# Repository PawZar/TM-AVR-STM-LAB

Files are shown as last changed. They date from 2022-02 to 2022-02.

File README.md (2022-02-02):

# Projekt centrali alarmowej
## TM-AVR-STM-LAB

Centrala alarmowa z hasłem , 6-wejść typu NC oraz wyjściem przekaźnika naruszenia typu NO.

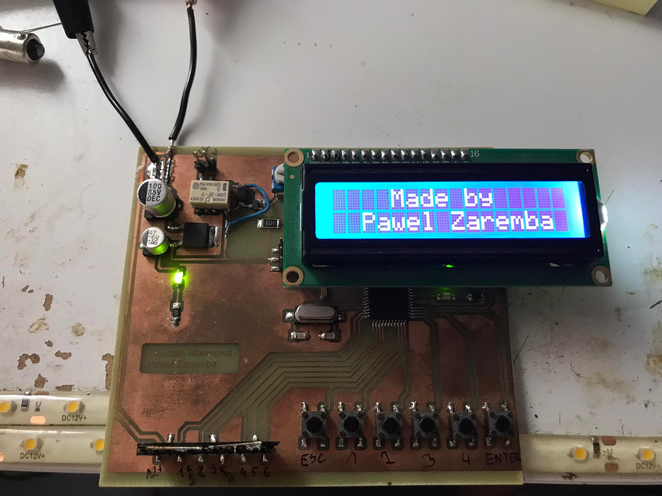
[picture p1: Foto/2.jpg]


## Cechy projektu:
* MCU: AtMega32A w obudowie TQFP44
* Wyświetlacz 2x16 ze sterownikiem HD44780
* Zasilanie 12V DC-IN Max:1,2A
* Zasilacznie czujek 12V DC ~1A obc.
* Wyjście naruszenia typu NO ~1A obciążenie styków
* Wejścia czujek NC wyzwalane stanem niskim
* Pamięć naruszeń
* Kontrola kontrastu wyświetlacza
* Diody LED statusu centrali (alarm,uzbrojenie,stan spoczynku,odliczanie)
* 6 przycisków w roli klawiatury (ESC,1-4,ENTER)
* Dioda LED zasilania

## Działanie centrali:

Centrala posiada 2 tryby, uzbrojony oraz nieuzbrojony. Po wciśnięciu przycisku ENTER następuje przejście do funkcji wpisywania hasła.
Do wpisywania hasła dostępne mamy przyciski 1-4, ENTER oraz ESC który kasuje błędnie wpisaną liczbę .
Po poprawnym wpisaniu hasła następuje odliczanie 20sekund symulujące czas na wyjście z mieszkania. Po upływie czasu uzbrajania centrali,
wejścia czujek aktywują się. Wejścia ustawione są w tryb NC ze zwarciem do GND, kiedy jedna z czujek przez minimum 1,6sek 
zostanie aktywowana zaczyna się przejście do funkcji wpisywania hasła na które ma się ponowne 20sekund. Po upływie tego czasu,
bądź 3-krotnym złym wpisaniu hasła następuje wyzwolenie alarmu i załączenie wyjścia. Podczas trwanai alarmu można przejść do funkcji 
wpisywania hasła przyciskiem ENTER. Po rozbrojeniu centrali po alarmie zapamiętane zostaje zdarzenie naruszenia systemu, po następnym uzbrojeniu
centrali błąd się kasuje.

## Mikrokontroler Atmega32A:

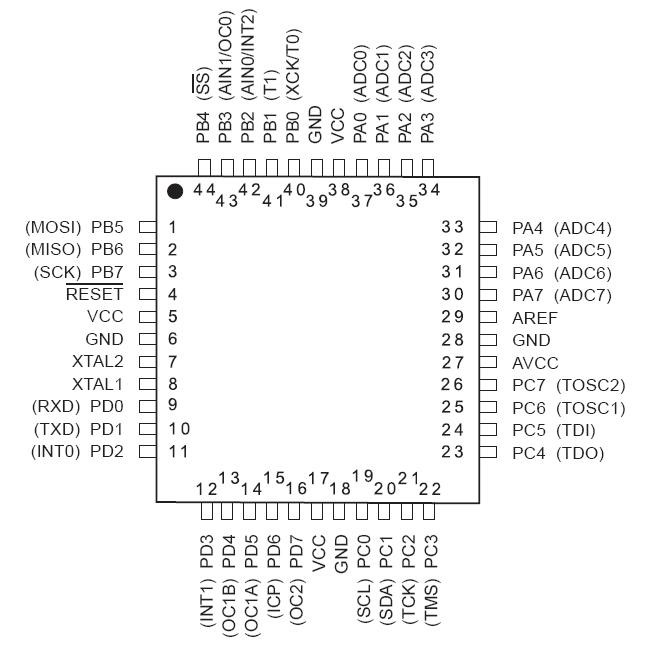
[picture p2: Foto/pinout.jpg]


 * Taktowanie w projekcie: 16MHz zewnętrzne
 * Zasilanie układu: 5V DC
 * Programowanie : złącze ISP
 * 1kB EEPROM
 * 2kB SRAM
 * 32kB flash
 
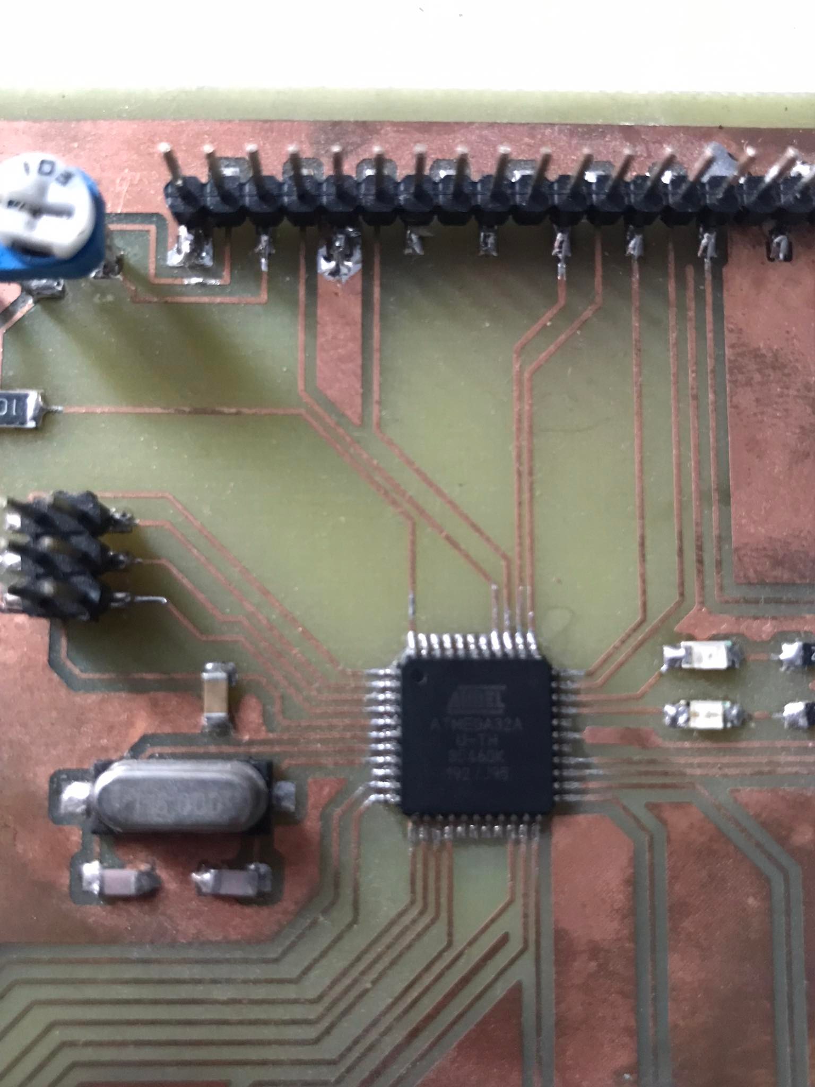
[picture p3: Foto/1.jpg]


## Zdjęcia schematu oraz płytki z programu EAGLE:

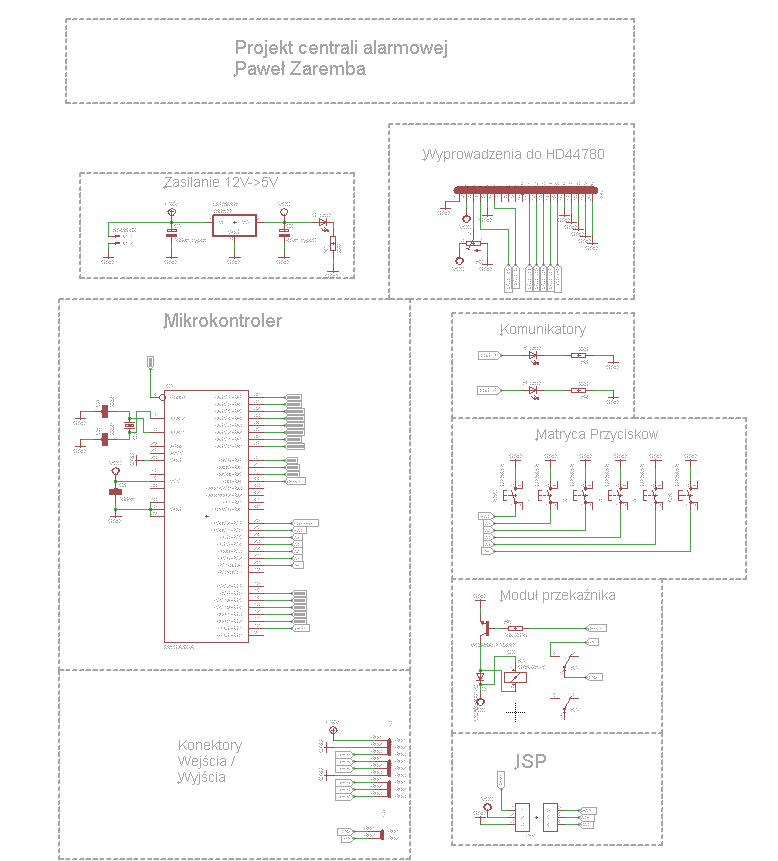
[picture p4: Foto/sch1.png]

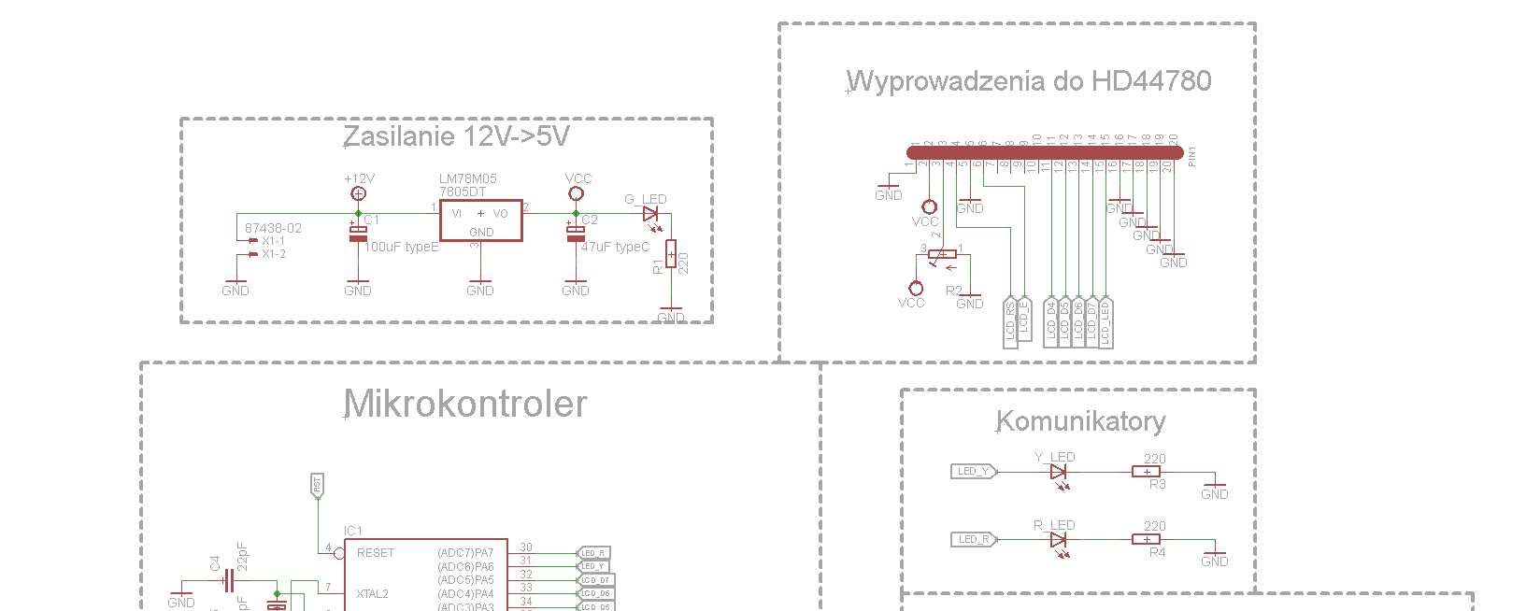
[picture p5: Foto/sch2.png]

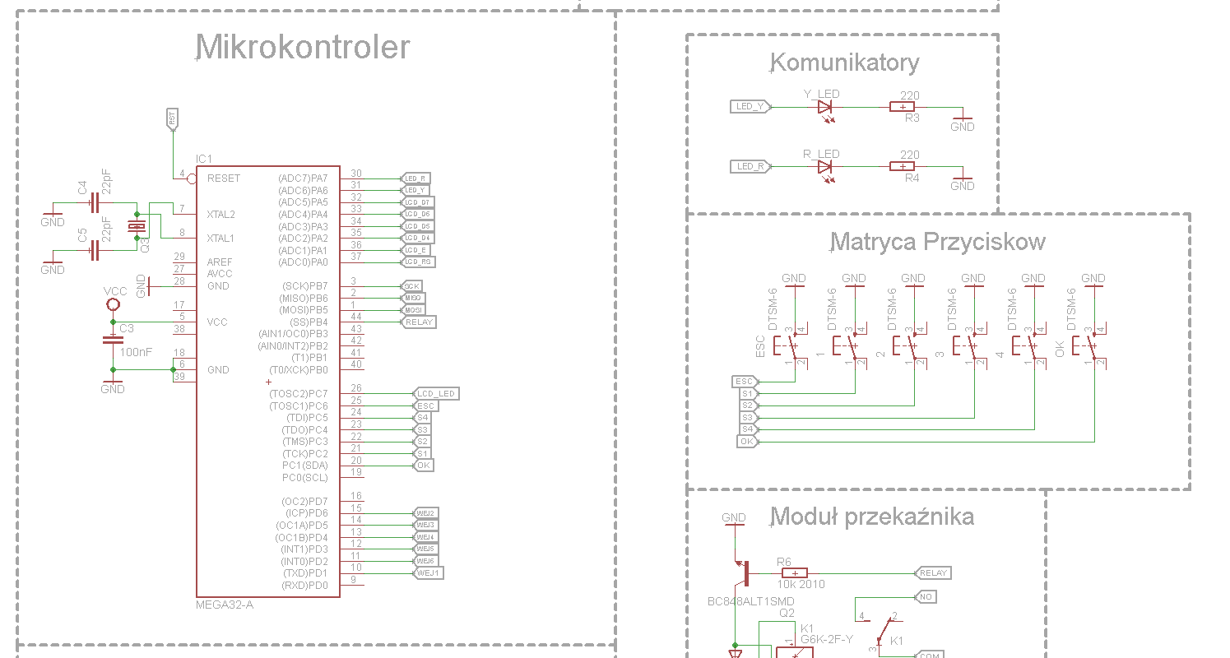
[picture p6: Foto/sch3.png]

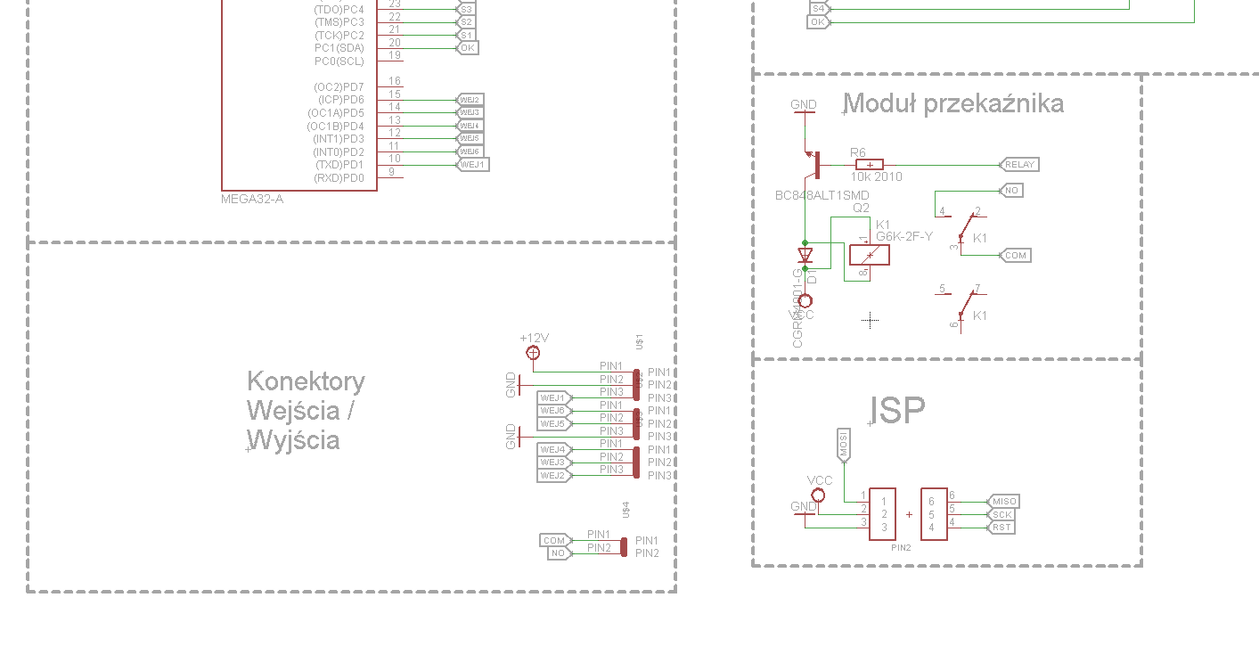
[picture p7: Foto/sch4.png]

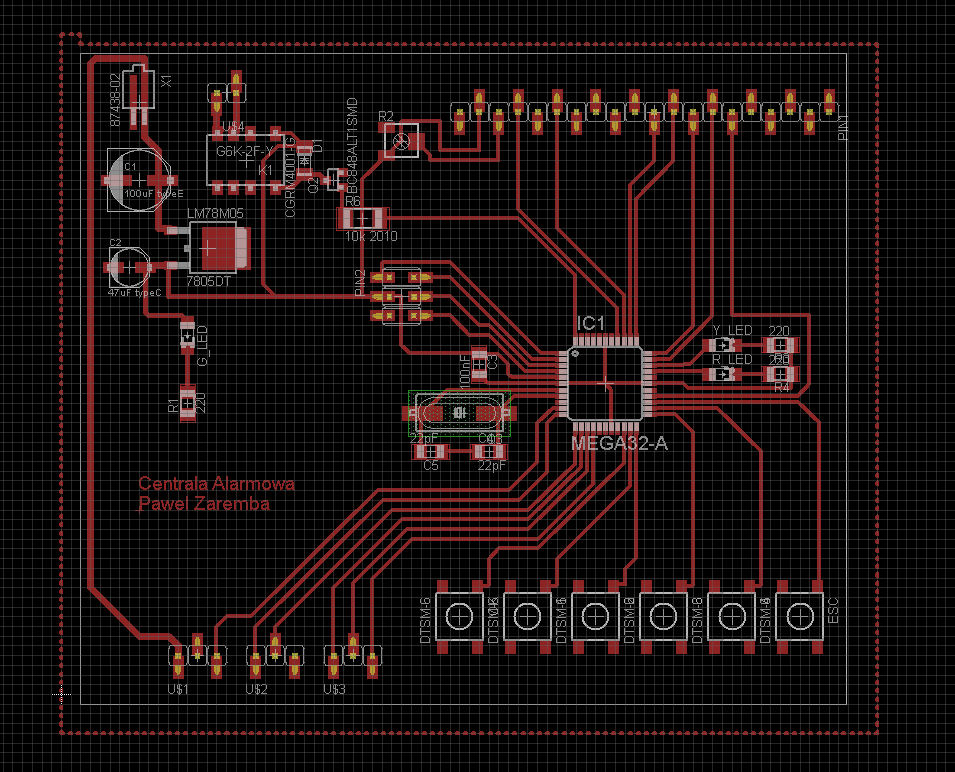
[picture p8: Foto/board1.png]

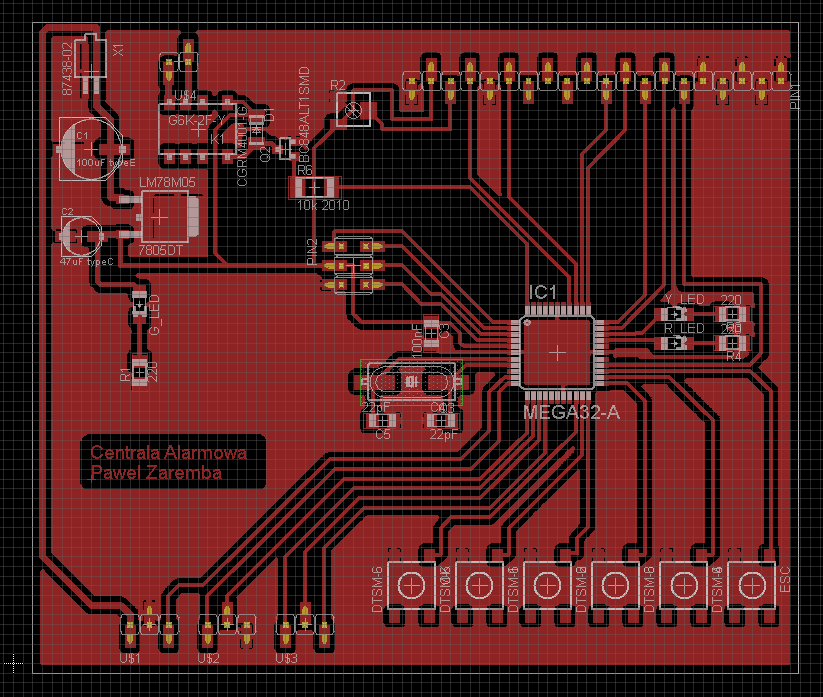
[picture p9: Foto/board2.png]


## Zdjęcia wykonanego układu:


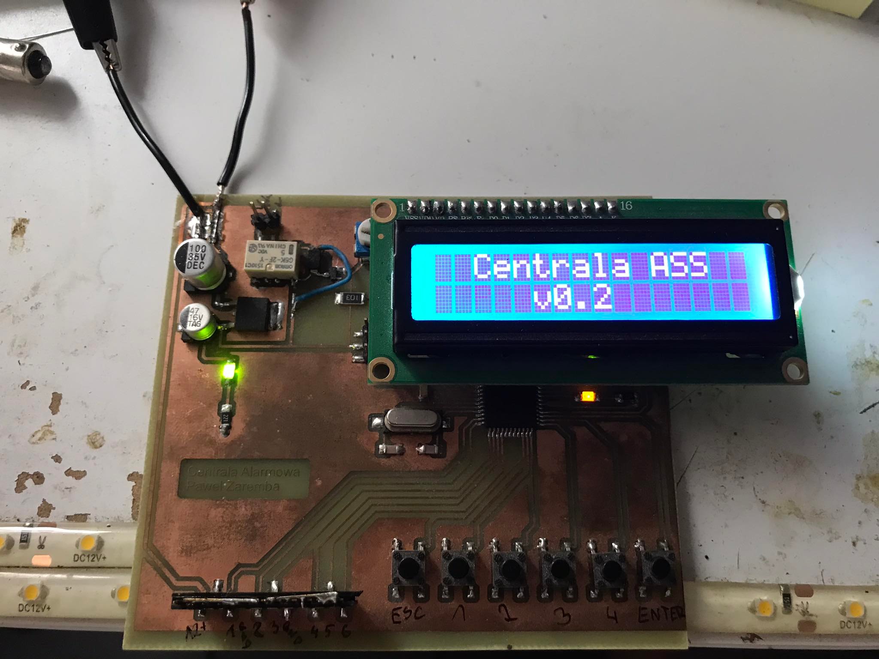
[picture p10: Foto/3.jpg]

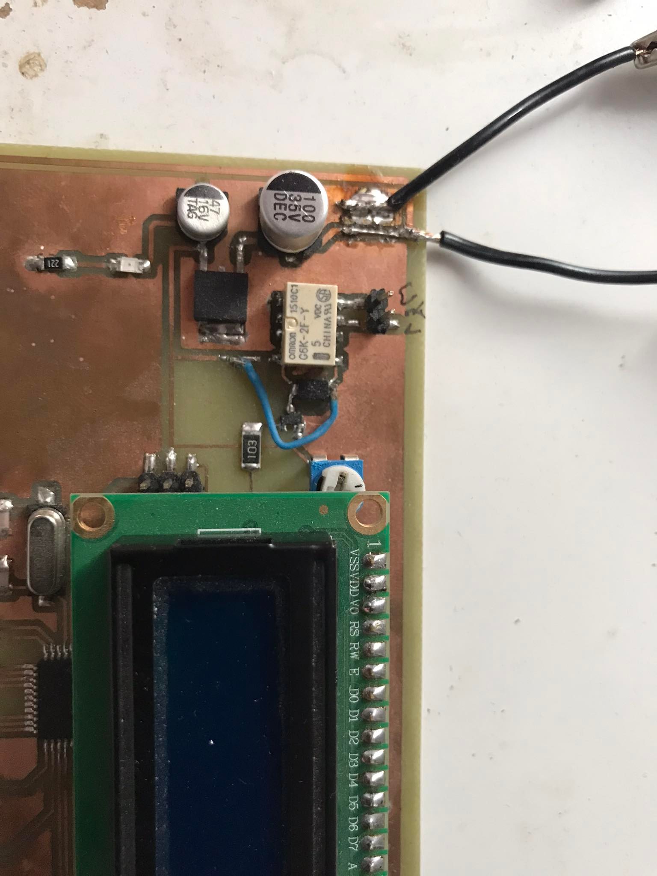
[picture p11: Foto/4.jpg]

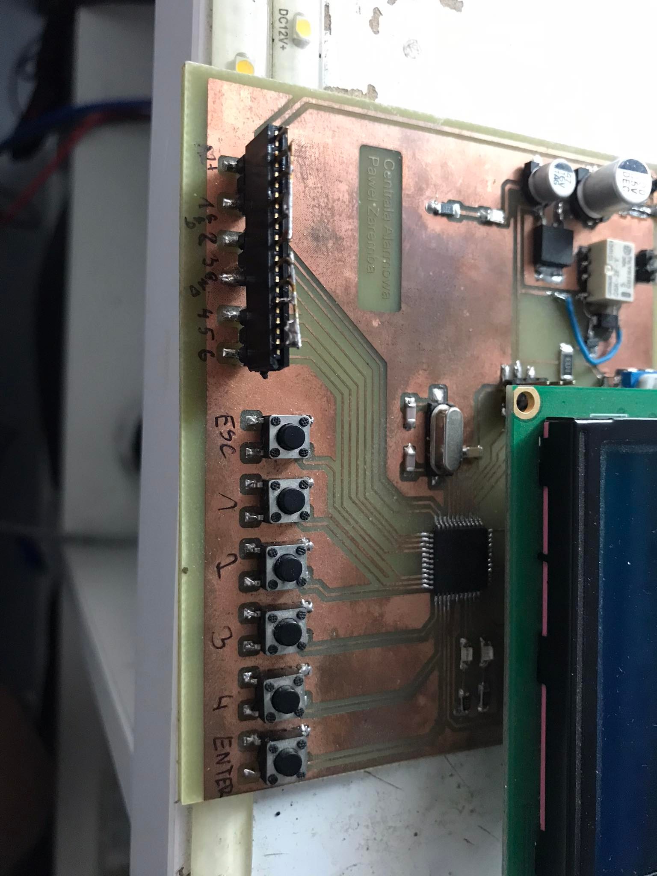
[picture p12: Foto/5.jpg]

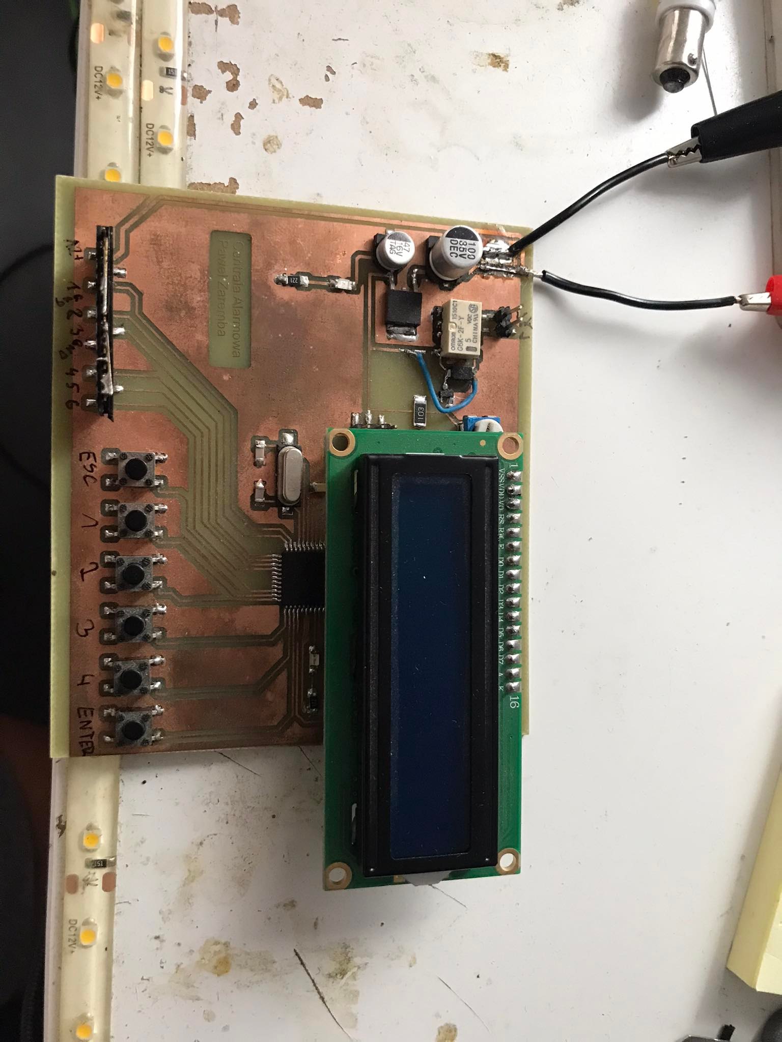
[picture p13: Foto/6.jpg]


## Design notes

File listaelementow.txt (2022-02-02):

Partlist

Exported from alarm1.sch at 2021-03-21 15:37:58

EAGLE Version 6.3.0 Copyright (c) 1988-2012 CadSoft

Assembly variant: 

Part     Value           Device          Package          Library                        Sheet

1        DTSM-6          DTSM-6          DTSM-6           switch-tact                    1
2        DTSM-6          DTSM-6          DTSM-6           switch-tact                    1
3        DTSM-6          DTSM-6          DTSM-6           switch-tact                    1
4        DTSM-6          DTSM-6          DTSM-6           switch-tact                    1
C1       100uF typeE     CPOL-EUE        PANASONIC_E      resistor                       1
C2       47uF typeC      CPOL-EUC        PANASONIC_C      resistor                       1
C3       100nF           C-EUC1206       C1206            resistor                       1
C4       22pF            C-EUC1206       C1206            resistor                       1
C5       22pF            C-EUC1206       C1206            resistor                       1
D1       CGRM4001-G      CGRM4001-G      SOD-123_MINI-SMA diode                          1
ESC      DTSM-6          DTSM-6          DTSM-6           switch-tact                    1
G_LED                    LEDCHIPLED_1206 CHIPLED_1206     led                            1
IC1      MEGA32-A        MEGA32-A        TQFP44           atmel                          1
K1       G6K-2F-Y        G6K-2F-Y        G6K-2F-Y         relay                          1
LM78M05  7805DT          7805DT          TO252            linear                         1
OK       DTSM-6          DTSM-6          DTSM-6           switch-tact                    1
PIN1                     SINGLE1X20      SINGLE1X20       con-pinheaderSMD2,54(gold_pin) 1
PIN2                     2X3_GOLDPIN     GOLD2X3          con-pinheaderSMD2,54(gold_pin) 1
Q2       BC848ALT1SMD    BC848ALT1SMD    SOT23            transistor-npn                 1
Q3                       CRYSTALHC49UP   HC49UP           crystal                        1
R1       220             R-EU_R1206      R1206            resistor                       1
R2                       R-TRIMM3314J    RTRIM3314J       resistor                       1
R3       220             R-EU_R1206      R1206            resistor                       1
R4       220             R-EU_R1206      R1206            resistor                       1
R6       10k 2010        R-EU_R2010      R2010            resistor                       1
R_LED                    LEDCHIPLED_1206 CHIPLED_1206     led                            1
U$1      GOLDPIN_SMD_1X3 GOLDPIN_SMD_1X3 GOLDPINSMD1X3    con-pinheaderSMD2,54-1x4       1
U$2      GOLDPIN_SMD_1X3 GOLDPIN_SMD_1X3 GOLDPINSMD1X3    con-pinheaderSMD2,54-1x4       1
U$3      GOLDPIN_SMD_1X3 GOLDPIN_SMD_1X3 GOLDPINSMD1X3    con-pinheaderSMD2,54-1x4       1
U$4      GOLDPIN_SMD_1X2 GOLDPIN_SMD_1X2 GOLDPINSMD1X2    con-pinheaderSMD2,54-1x4       1
X2       87438-02        87438-02        87438-02         con-molex                      1
Y_LED                    LEDCHIPLED_1206 CHIPLED_1206     led                            1

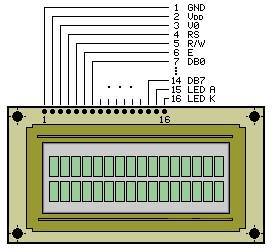
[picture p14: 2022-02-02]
Foto/wysw.jpg

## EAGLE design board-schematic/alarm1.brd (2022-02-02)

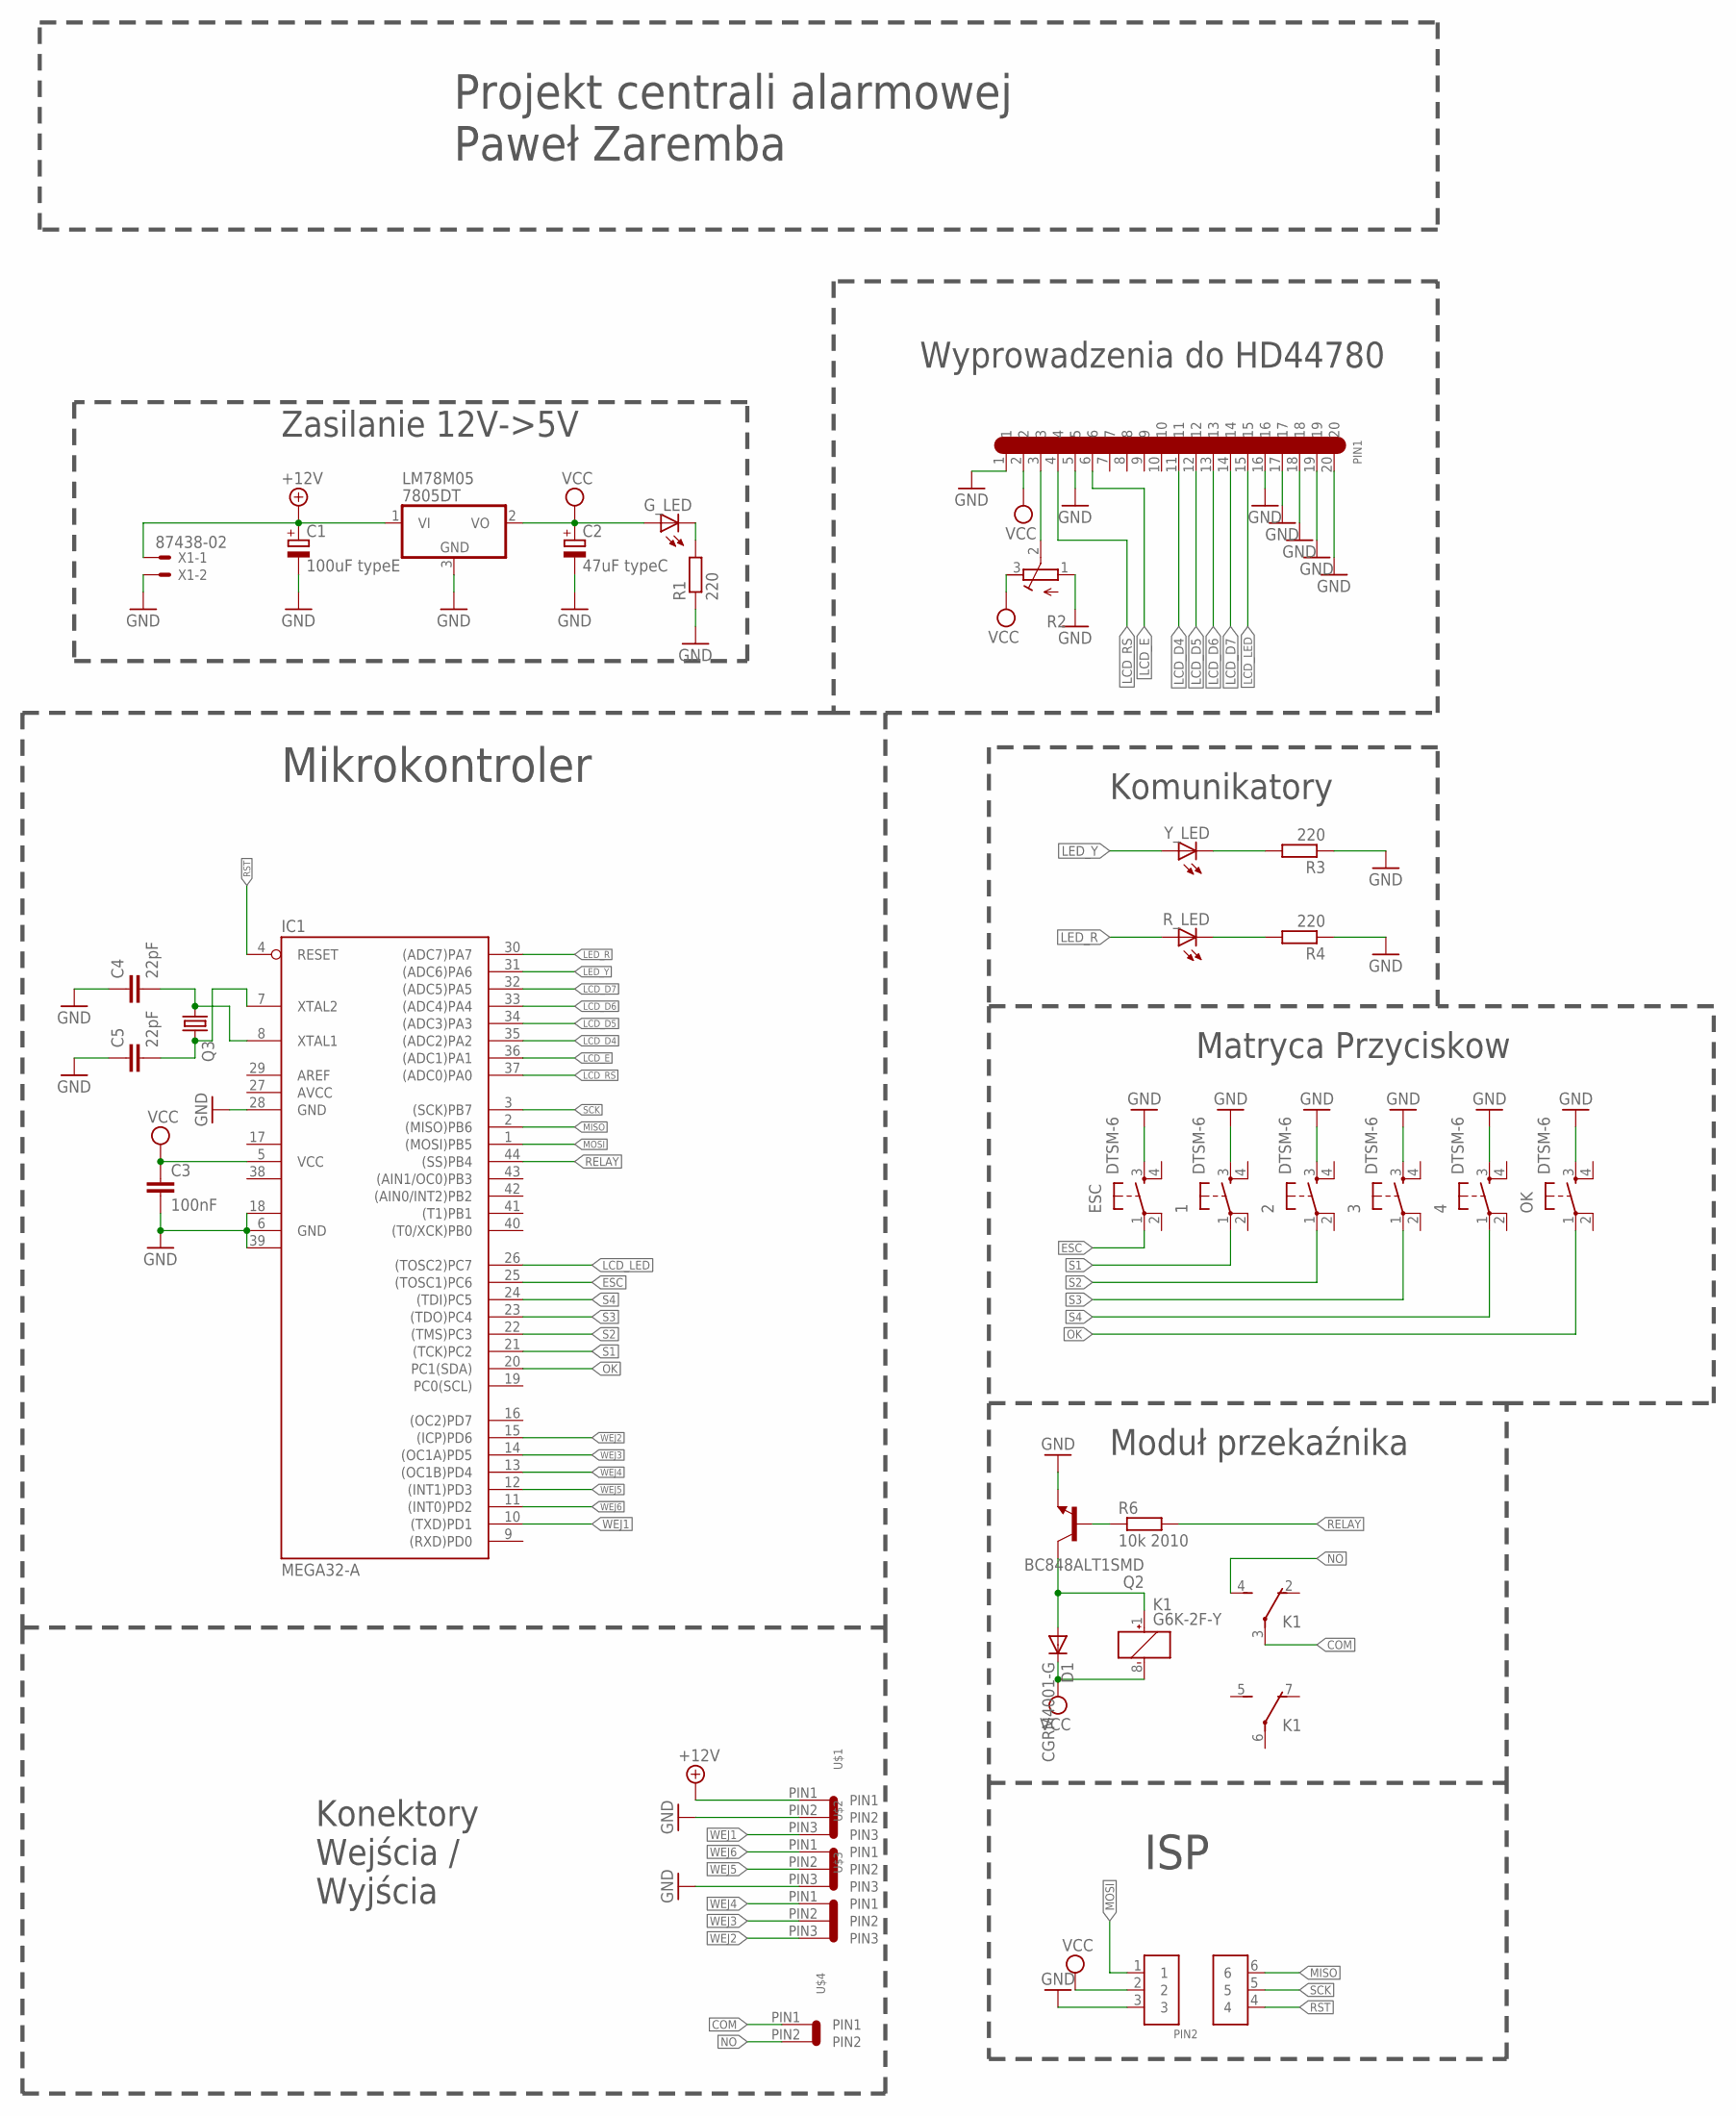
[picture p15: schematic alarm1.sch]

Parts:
1, 2, 3, 4: DTSM-6
C1: 100uF typeE; PANASONIC_E
C2: 47uF typeC; PANASONIC_C
C3: 100nF; C1206
C4, C5: 22pF; C1206
D1: CGRM4001-G; SOD-123_MINI-SMA
ESC: DTSM-6
G_LED: LEDCHIPLED_1206; CHIPLED_1206
IC1: MEGA32-A; TQFP44
K1: G6K-2F-Y
LM78M05: 7805DT; TO252
OK: DTSM-6
PIN1: SINGLE1X20
PIN2: 2X3_GOLDPIN; GOLD2X3
Q2: BC848ALT1SMD; SOT23
Q3: CRYSTALHC49UP; HC49UP
R1, R3, R4: 220; R1206
R2: R-TRIMM3314J; RTRIM3314J
R6: 10k 2010; R2010
R_LED: LEDCHIPLED_1206; CHIPLED_1206
U$1, U$2, U$3: GOLDPIN_SMD_1X3; GOLDPINSMD1X3
U$4: GOLDPIN_SMD_1X2; GOLDPINSMD1X2
X1: 87438-02
Y_LED: LEDCHIPLED_1206; CHIPLED_1206

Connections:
+12V: C1.+, LM78M05.1 (VI), U$1.PIN1, X1.1
AVCC: IC1.27 (AVCC)
COM: K1.3, U$4.PIN1
CRYSTAL_L: C5.2, IC1.7 (XTAL2), Q3.2
CRYSTAL_R: C4.2, IC1.8 (XTAL1), Q3.1
ESC: ESC.1, IC1.25 ((TOSC1)PC6)
GND: 1.3, 2.3, 3.3, 4.3, C1.-, C2.-, C3.2, C4.1, C5.1, ESC.3, IC1.6 (GND), IC1.18 (GND1), IC1.28 (GND), IC1.39 (GND2), LM78M05.3 (GND), OK.3, PIN1.1, PIN1.5, PIN1.16, PIN1.17, PIN1.18, PIN1.19, PIN1.20, PIN2.3, Q2.2 (E), R1.1, R2.1 (E), R3.1, R4.1, U$1.PIN2, U$2.PIN3, X1.2
LCD_D4: IC1.35 ((ADC2)PA2), PIN1.11
LCD_D5: IC1.34 ((ADC3)PA3), PIN1.12
LCD_D6: IC1.33 ((ADC4)PA4), PIN1.13
LCD_D7: IC1.32 ((ADC5)PA5), PIN1.14
LCD_E: IC1.36 ((ADC1)PA1), PIN1.6
LCD_LED: IC1.26 ((TOSC2)PC7), PIN1.15
LCD_RS: IC1.37 ((ADC0)PA0), PIN1.4
LED_R: IC1.30 ((ADC7)PA7), R_LED.A
LED_Y: IC1.31 ((ADC6)PA6), Y_LED.A
MISO: IC1.2 ((MISO)PB6), PIN2.6
MOSI: IC1.1 ((MOSI)PB5), PIN2.1
unnamed: D1.A, K1.1 (+), Q2.3 (C)
unnamed: G_LED.C, R1.2
unnamed: PIN1.3, R2.2 (S)
unnamed: R3.2, Y_LED.C
unnamed: R4.2, R_LED.C
unnamed: Q2.1 (B), R6.1
NO: K1.4 (S), U$4.PIN2
OK: IC1.20 (PC1(SDA)), OK.1
RELAY: IC1.44 ((SS)PB4), R6.2
RST: IC1.4 (RESET), PIN2.4
S1: 1.1, IC1.21 ((TCK)PC2)
S2: 2.1, IC1.22 ((TMS)PC3)
S3: 3.1, IC1.23 ((TDO)PC4)
S4: 4.1, IC1.24 ((TDI)PC5)
SCK: IC1.3 ((SCK)PB7), PIN2.5
VCC: C2.+, C3.1, D1.C, G_LED.A, IC1.5 (VCC), K1.8 (-), LM78M05.2 (VO), PIN1.2, PIN2.2, R2.3 (A)
VCC1: IC1.17 (VCC1)
VCC2: IC1.38 (VCC2)
WEJ1: IC1.10 ((TXD)PD1), U$1.PIN3
WEJ2: IC1.15 ((ICP)PD6), U$3.PIN3
WEJ3: IC1.14 ((OC1A)PD5), U$3.PIN2
WEJ4: IC1.13 ((OC1B)PD4), U$3.PIN1
WEJ5: IC1.12 ((INT1)PD3), U$2.PIN2
WEJ6: IC1.11 ((INT0)PD2), U$2.PIN1

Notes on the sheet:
Zasilanie 12V->5V
Wyprowadzenia do HD44780
Komunikatory
Matryca Przyciskow
ISP
Moduł przekaźnika
Konektory Wejścia / Wyjścia
Mikrokontroler
Projekt centrali alarmowej Paweł Zaremba

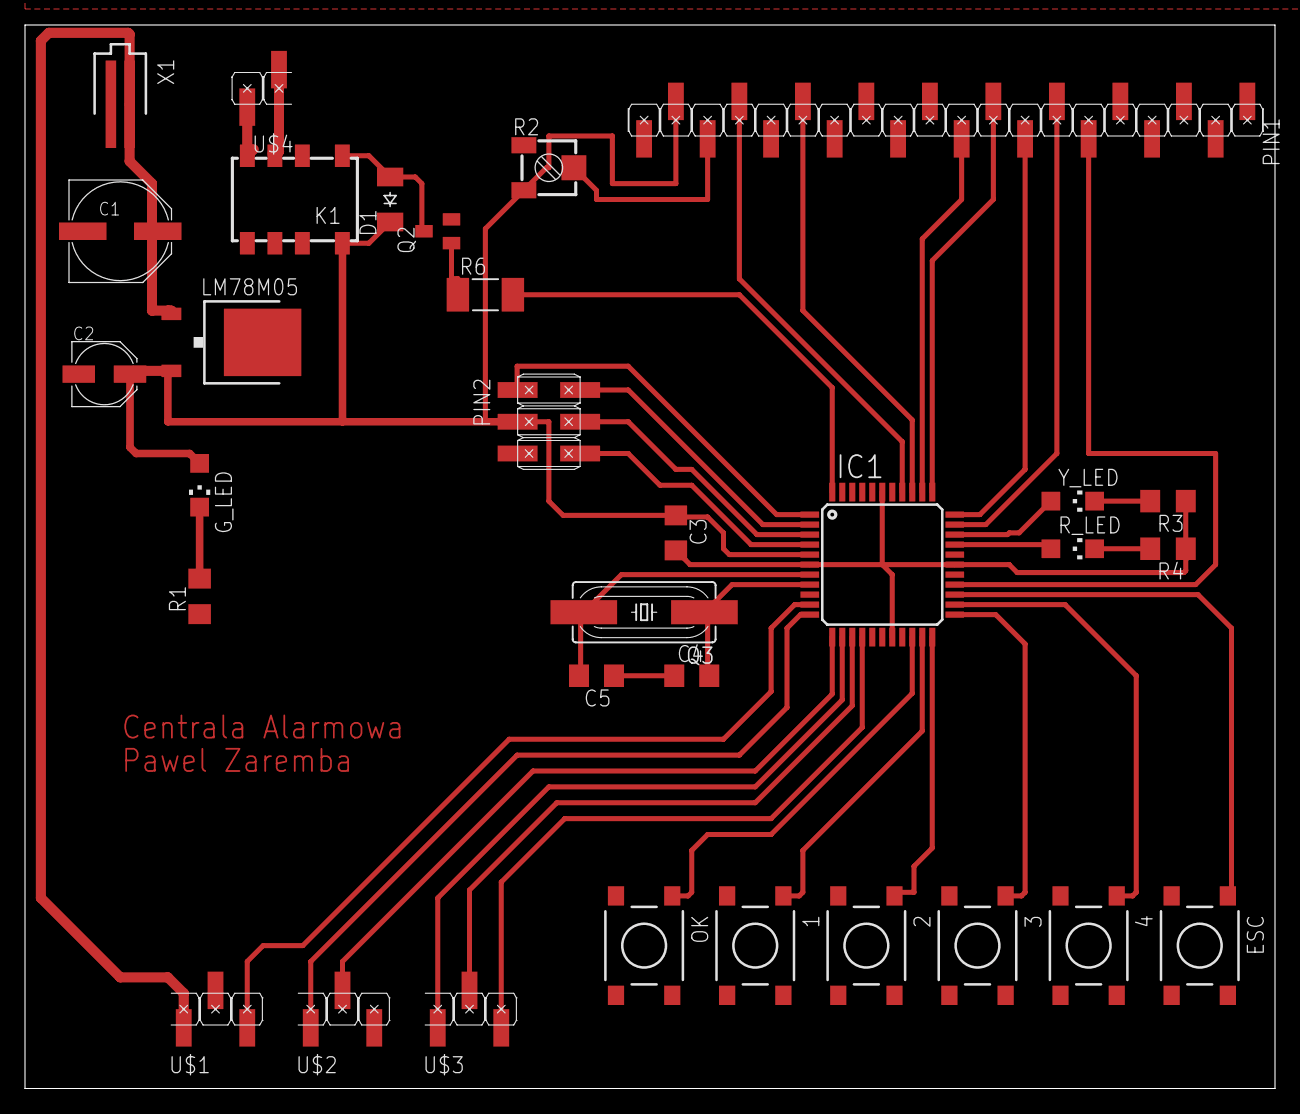
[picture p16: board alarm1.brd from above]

Board: 2 copper layers, 100.0 x 85.1 mm, 32 parts (0 on the bottom side), 39 nets.

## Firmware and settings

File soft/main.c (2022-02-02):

/*
 * main.c
 *
 *  Created on: 09-03-2021
 *      Author: Pawel
 */
#include <avr/io.h>
#include <util/delay.h>
#include <avr/alarm/HD44780.h>
#include "avr/alarm/HD44780.c"

#define LEDy (1<<PA6) //zolta dioda statusu
#define LEDr (1<<PA7) //czerwona dioda uzbrojenia

#define esc (1<<PC2) // esc
#define jeden (1<<PC3) // 1
#define dwa (1<<PC4) // 2
#define trzy (1<<PC5) // 3
#define cztery (1<<PC6) // 4
#define ok (1<<PC7) //  ok / uzbrajanie

#define relay (1<<PD0) // przekaznik

#define wej1 (1<<PD2) // wejscie Z1
#define wej2 (1<<PD3) // wejscie Z2
#define wej3 (1<<PD4) // wejscie Z3
#define wej4 (1<<PD5) // wejscie Z4
#define wej5 (1<<PD6) // wejscie Z5
#define wej6 (1<<PD7) // wejscie Z6


int main(void)
{
//wyjscia
DDRA |= LEDy;
DDRA |= LEDr;
DDRD |= relay;
//wejscia
PORTC |= esc;
PORTC |= jeden;
PORTC |= dwa;
PORTC |= trzy;
PORTC |= cztery;
PORTC |= ok;
PORTD |= wej1;
PORTD |= wej2;
PORTD |= wej3;
PORTD |= wej4;
PORTD |= wej5;
PORTD |= wej6;
//inicjalizacja LCD
_delay_ms(10);

LCD_Initalize();
LCD_Clear();
LCD_GoTo(0,0);

_delay_ms(10);
//deklaracja zmiennych
int niepoprawnehaslo=0;
int wyjsciowa=0;
int uzbrojenie=0;
int haslopoprawne=0;
int alarm=0;
int naruszenie1=0;
int naruszenie2=0;
int naruszenie3=0;
int naruszenie4=0;
int naruszenie5=0;
int naruszenie6=0;
int wlamanie=0;
int timer=0;	//100ms kazdy cykl

powitanie(); // wyswietl ekran startowy


while(1){
	if((uzbrojenie==0)&&(alarm==0)){
	ekran_start(wlamanie, timer);
	}

	if(!(PINC & ok))
	{
		//funkcje wpisania hasla

		wyjsciowa=funkcjaHasla();
		_delay_ms(250);
	}

	if(wyjsciowa>=1)
	{
	switch(wyjsciowa)
		{
	case 0:

	break;

	case 1:
		//haslo niepoprawne
		niepoprawnehaslo++;
		wysHasloNiepoprawne();
		wyjsciowa=0;
		if(niepoprawnehaslo>=3){
			alarm=1;
			niepoprawnehaslo=0;
			uzbrojenie=1;
		}
		break;

	case 2:
		//haslo poprawne

		niepoprawnehaslo=0;
		wysHasloPoprawne();
		if(uzbrojenie==0){
		wlamanie=0;
		OdliczanieDoUzbrojenia();
		uzbrojenie=1;
		haslopoprawne=0;
		}

		else if(uzbrojenie==1){
		if(PIND & relay){
			PORTD ^= relay;
		}
		uzbrojenie=0;
		alarm=0;
		naruszenie1=0;
		naruszenie2=0;
		naruszenie3=0;
		naruszenie4=0;
		naruszenie5=0;
		naruszenie6=0;
		}
		wyjsciowa=0;
		break;

	case 3:
		//cofnij dzialanie , nie rob nic
		wyjsciowa=0;
		break;



		}
	}

	if((uzbrojenie==1)&&(alarm==0))
	{
		stanUzbrojony();

	if(PIND & wej1)
	{
	naruszenie1++;
		if(naruszenie1>=15){
			wyjsciowa=funkcjaHasla();
			naruszenie1=16;
		}
	}
	else if(!(PIND & wej1)){
		if(naruszenie1>=1){
		naruszenie1--;
		}
	}


	if(PIND & wej2)
	{
	naruszenie2++;
		if(naruszenie2>=15){
			wyjsciowa=funkcjaHasla();
			naruszenie2=16;
		}
	}
	else if(!(PIND & wej2)){
		if(naruszenie2>=1){
		naruszenie2--;
		}
	}


	if(PIND & wej3)
	{
	naruszenie3++;
		if(naruszenie3>=15){
			wyjsciowa=funkcjaHasla();
			naruszenie3=16;
		}
	}
	else if(!(PIND & wej3)){
		if(naruszenie3>=1){
		naruszenie3--;
		}
	}


	if(PIND & wej4)
	{
	naruszenie4++;
		if(naruszenie4>=15){
			wyjsciowa=funkcjaHasla();
			naruszenie4=16;
		}
	}
	else if(!(PIND & wej4)){
		if(naruszenie4>=1){
		naruszenie4--;
		}
	}


	if(PIND & wej5)
	{
	naruszenie5++;
		if(naruszenie5>=15){
			wyjsciowa=funkcjaHasla();
			naruszenie5=16;
		}
	}
	else if(!(PIND & wej5)){
		if(naruszenie5>=1){
		naruszenie5--;
		}
	}

	if(PIND & wej6)
	{
	naruszenie6++;
		if(naruszenie6>=15){
			wyjsciowa=funkcjaHasla();
			naruszenie6=16;
		}
	}
	else if(!(PIND & wej6)){
		if(naruszenie6>=1){
		naruszenie6--;
		}
	}

	}


	if(alarm==1)
	{
		if(!(PIND & relay)){
			PORTD ^= relay;
		}
		if(!(PINA & LEDr)){
		PORTA ^= LEDr;
		}
		wysAlarm();
		wlamanie=1;
	}


	_delay_ms(100); //globalny timer
	timer++;
	if(timer>=100){
		timer=0;
	}
	}
}

void powitanie()
{
	PORTA ^= LEDr;
	PORTA ^= LEDy;
	LCD_Clear();
	LCD_GoTo(2,0);
	LCD_WriteText("Centrala ASS");
	LCD_GoTo(5,1);
	LCD_WriteText("v0.2");
	_delay_ms(2500);
	PORTA ^= LEDr;
	PORTA ^= LEDy;
	LCD_Clear();
	LCD_GoTo(4,0);
	LCD_WriteText("Made by");
	LCD_GoTo(2,1);
	LCD_WriteText("Pawel Zaremba");
	_delay_ms(1500);
}


void ekran_start(int wlam, int time)
{
	int t;
	int t1;
	if(PINA & LEDr){
		PORTA^= LEDr;
	}
	if(PINA & LEDy){
		PORTA^= LEDy;
	}
	if(PINA & relay){
		PORTA^= relay;
	}
	t=time%20;
	t1=time%40;
	LCD_GoTo(0,0);
	LCD_WriteText("  Centrala ASS  ");
if(wlam==0)
{
	LCD_GoTo(0,1);
	LCD_WriteText("Brak powiadomien");
	if((t==0)&&(t1!=0)){
		PORTA ^= LEDy;
	}
	if((t==0)&&(t1==0)){
		PORTA ^=LEDy;
	}
}
if(wlam==1)
{
			if((t==0)&&(t1!=0)){
				PORTA ^= LEDy;
				PORTA^= LEDr;

			}
			if((t==0)&&(t1==0)){
				PORTA ^=LEDy;
				PORTA^= LEDr;
			}
	LCD_GoTo(0,1);
	LCD_WriteText("wys. Naruszenie!");

}
}

int funkcjaHasla(){
	int wyjsciowa=0;
	int haslo[5];
	haslo[0] = 3;
	haslo[1] = 4;
	haslo[2] = 1;
	haslo[3] = 1;
	haslo[4] = 3;
	int wpisywanehaslo[5];
	wpisywanehaslo[0] = 0;
	wpisywanehaslo[1] = 0;
	wpisywanehaslo[2] = 0;
	wpisywanehaslo[3] = 0;
	wpisywanehaslo[4] = 0;
	int a=0; // wpisano liczbe
	//int wyjscie=0;
	int sprawdzanie=0;
	int time=0;
	int poprawne[5];
	poprawne[0]=0;
	poprawne[1]=0;
	poprawne[2]=0;
	poprawne[3]=0;
	poprawne[4]=0;
	if(PINA & LEDr){
		PORTA^= LEDr;
	}
	if(PINA & LEDy){
		PORTA^= LEDy;
	}
	_delay_ms(500);
		for(int i=0;i<=150;i++)
		{
		if(!(PINC & jeden))
		{

			wpisywanehaslo[a]=1;

			if(wpisywanehaslo[a]==haslo[a]){
				poprawne[a]=1;
			}
			else{
				poprawne[a]=0;
			}
			a++;
			_delay_ms(250);
		}
		else if(!(PINC & dwa))
		{

			wpisywanehaslo[a]=2;
			if(wpisywanehaslo[a]==haslo[a]){
				poprawne[a]=1;
			}
			else{
				poprawne[a]=0;
			}
			a++;
			_delay_ms(250);
		}
		else if(!(PINC & trzy))
		{

			wpisywanehaslo[a]=3;
			if(wpisywanehaslo[a]==haslo[a]){
				poprawne[a]=1;
			}
			else{
				poprawne[a]=0;
			}
			a++;
			_delay_ms(250);
		}
		else if(!(PINC & cztery))
		{

			wpisywanehaslo[a]=4;
			if(wpisywanehaslo[a]==haslo[a]){
				poprawne[a]=1;
			}
			else{
				poprawne[a]=0;
			}
			a++;
			_delay_ms(250);
		}
		if(a==0){
			LCD_Clear();
			LCD_GoTo(0,0);
			LCD_WriteText("Wpisz Haslo:");

		}
		else if(a==1){
			LCD_Clear();
			LCD_GoTo(0,0);
			LCD_WriteText("Wpisz Haslo:");
			LCD_GoTo(0,1);
			LCD_WriteText("*");
		}
		else if(a==2){
			LCD_Clear();
			LCD_GoTo(0,0);
			LCD_WriteText("Wpisz Haslo:");
			LCD_GoTo(0,1);
			LCD_WriteText("**");
		}
		else if(a==3){
			LCD_Clear();
			LCD_GoTo(0,0);
			LCD_WriteText("Wpisz Haslo:");
			LCD_GoTo(0,1);
			LCD_WriteText("***");
		}
		else if(a==4){
			LCD_Clear();
			LCD_GoTo(0,0);
			LCD_WriteText("Wpisz Haslo:");
			LCD_GoTo(0,1);
			LCD_WriteText("****");
		}
		else if(a==5){
			LCD_Clear();
			LCD_GoTo(0,0);
			LCD_WriteText("Wpisz Haslo:");
			LCD_GoTo(0,1);
			LCD_WriteText("*****");
		}
		if(!(PINC & esc))
		{

			wyjsciowa=3;
			_delay_ms(250);
			break;
		}
		if(!(PINC & ok)){
			_delay_ms(250);
			break;

		}

		_delay_ms(100);



	}
	if(wyjsciowa==3){

	}
	else{
		if((poprawne[0]==1)&&(poprawne[1]==1)&&(poprawne[2]==1)&&(poprawne[3]==1)&&(poprawne[4]==1)){
			wyjsciowa=2;
		}
		else{
			wyjsciowa=1;
		}
	}

	return wyjsciowa;
}

void wysHasloNiepoprawne(){
	LCD_Clear();
	LCD_GoTo(5,0);
	LCD_WriteText("Haslo");
	LCD_GoTo(2,1);
	LCD_WriteText("Niepoprawne!");
	_delay_ms(800);
	LCD_Clear();
	_delay_ms(600);
	LCD_GoTo(5,0);
	LCD_WriteText("Haslo");
	LCD_GoTo(2,1);
	LCD_WriteText("Niepoprawne!");
	_delay_ms(800);
	LCD_Clear();
	_delay_ms(600);
	LCD_GoTo(5,0);
	LCD_WriteText("Haslo");
	LCD_GoTo(2,1);
	LCD_WriteText("Niepoprawne!");
	_delay_ms(800);
	LCD_Clear();
}

void wysHasloPoprawne(){
	LCD_Clear();
		LCD_GoTo(5,0);
		LCD_WriteText("Haslo");
		LCD_GoTo(2,1);
		LCD_WriteText("Poprawne");
		_delay_ms(1000);
		LCD_Clear();
}

void OdliczanieDoUzbrojenia(){
	if(PINA & LEDr){
		PORTA^= LEDr;
	}
	if(PINA & LEDy){
		PORTA^= LEDy;
	}
	LCD_Clear();
	PORTA^= LEDy;
	LCD_GoTo(0,0);
	LCD_WriteText("Uzbrajanie");
	LCD_GoTo(0,1);
	LCD_WriteText("20s");
	_delay_ms(200);
	PORTA^= LEDy;
	_delay_ms(200);
	PORTA^= LEDy;
	_delay_ms(200);
	PORTA^= LEDy;
	_delay_ms(200);
	PORTA^= LEDy;
	_delay_ms(200);
	PORTA^= LEDy;
	LCD_GoTo(0,1);
	LCD_WriteText("19s");
	_delay_ms(200);
	PORTA^= LEDy;
	_delay_ms(200);
	PORTA^= LEDy;
	_delay_ms(200);
	PORTA^= LEDy;
	_delay_ms(200);
	PORTA^= LEDy;
	_delay_ms(200);
	PORTA^= LEDy;
	LCD_GoTo(0,1);
	LCD_WriteText("18s");
	_delay_ms(200);
	PORTA^= LEDy;
	_delay_ms(200);
	PORTA^= LEDy;
	_delay_ms(200);
	PORTA^= LEDy;
	_delay_ms(200);
	PORTA^= LEDy;
	_delay_ms(200);
	PORTA^= LEDy;
	LCD_GoTo(0,1);
	LCD_WriteText("17s");
	_delay_ms(200);
	PORTA^= LEDy;
	_delay_ms(200);
	PORTA^= LEDy;
	_delay_ms(200);
	PORTA^= LEDy;
	_delay_ms(200);
	PORTA^= LEDy;
	_delay_ms(200);
	PORTA^= LEDy;
	LCD_GoTo(0,1);
	LCD_WriteText("16s");
	_delay_ms(200);
	PORTA^= LEDy;
	_delay_ms(200);
	PORTA^= LEDy;
	_delay_ms(200);
	PORTA^= LEDy;
	_delay_ms(200);
	PORTA^= LEDy;
	_delay_ms(200);
	PORTA^= LEDy;
	LCD_GoTo(0,1);
	LCD_WriteText("15s");
	_delay_ms(200);
	PORTA^= LEDy;
	_delay_ms(200);
	PORTA^= LEDy;
	_delay_ms(200);
	PORTA^= LEDy;
	_delay_ms(200);
	PORTA^= LEDy;
	_delay_ms(200);
	PORTA^= LEDy;
	LCD_GoTo(0,1);
	LCD_WriteText("14s");
	_delay_ms(200);
	PORTA^= LEDy;
	_delay_ms(200);
	PORTA^= LEDy;
	_delay_ms(200);
	PORTA^= LEDy;
	_delay_ms(200);
	PORTA^= LEDy;
	_delay_ms(200);
	PORTA^= LEDy;
	LCD_GoTo(0,1);
	LCD_WriteText("13s");
	_delay_ms(200);
	PORTA^= LEDy;
	_delay_ms(200);
	PORTA^= LEDy;
	_delay_ms(200);
	PORTA^= LEDy;
	_delay_ms(200);
	PORTA^= LEDy;
	_delay_ms(200);
	PORTA^= LEDy;
	LCD_GoTo(0,1);
	LCD_WriteText("12s");
	_delay_ms(200);
	PORTA^= LEDy;
	_delay_ms(200);
	PORTA^= LEDy;
	_delay_ms(200);
	PORTA^= LEDy;
	_delay_ms(200);
	PORTA^= LEDy;
	_delay_ms(200);
	PORTA^= LEDy;
	LCD_GoTo(0,1);
	LCD_WriteText("11s");
	_delay_ms(200);
	PORTA^= LEDy;
	_delay_ms(200);
	PORTA^= LEDy;
	_delay_ms(200);
	PORTA^= LEDy;
	_delay_ms(200);
	PORTA^= LEDy;
	_delay_ms(200);
	PORTA^= LEDy;
	LCD_GoTo(0,1);
	LCD_WriteText("10s");
	_delay_ms(200);
	PORTA^= LEDy;
	_delay_ms(200);
	PORTA^= LEDy;
	_delay_ms(200);
	PORTA^= LEDy;
	_delay_ms(200);
	PORTA^= LEDy;
	_delay_ms(200);
	PORTA^= LEDy;
	LCD_Clear();
	LCD_GoTo(0,0);
	LCD_WriteText("Uzbrajanie");
	LCD_GoTo(0,1);
	LCD_WriteText("9s");
	_delay_ms(200);
	PORTA^= LEDy;
	_delay_ms(200);
	PORTA^= LEDy;
	_delay_ms(200);
	PORTA^= LEDy;
	_delay_ms(200);
	PORTA^= LEDy;
	_delay_ms(200);
	PORTA^= LEDy;
	LCD_GoTo(0,1);
	LCD_WriteText("8s");
	_delay_ms(200);
	PORTA^= LEDy;
	_delay_ms(200);
	PORTA^= LEDy;
	_delay_ms(200);
	PORTA^= LEDy;
	_delay_ms(200);
	PORTA^= LEDy;
	_delay_ms(200);
	PORTA^= LEDy;
	LCD_GoTo(0,1);
	LCD_WriteText("7s");
	_delay_ms(200);
	PORTA^= LEDy;
	_delay_ms(200);
	PORTA^= LEDy;
	_delay_ms(200);
	PORTA^= LEDy;
	_delay_ms(200);
	PORTA^= LEDy;
	_delay_ms(200);
	PORTA^= LEDy;
	LCD_GoTo(0,1);
	LCD_WriteText("6s");
	_delay_ms(200);
	PORTA^= LEDy;
	_delay_ms(200);
	PORTA^= LEDy;
	_delay_ms(200);
	PORTA^= LEDy;
	_delay_ms(200);
	PORTA^= LEDy;
	_delay_ms(200);
	PORTA^= LEDy;
	LCD_GoTo(0,1);
	LCD_WriteText("5s");
	_delay_ms(200);
	PORTA^= LEDy;
	_delay_ms(200);
	PORTA^= LEDy;
	_delay_ms(200);
	PORTA^= LEDy;
	_delay_ms(200);
	PORTA^= LEDy;
	_delay_ms(200);
	PORTA^= LEDy;
	LCD_GoTo(0,1);
	LCD_WriteText("4s");
	_delay_ms(200);
	PORTA^= LEDy;
	_delay_ms(200);
	PORTA^= LEDy;
	_delay_ms(200);
	PORTA^= LEDy;
	_delay_ms(200);
	PORTA^= LEDy;
	_delay_ms(200);
	PORTA^= LEDy;
	LCD_GoTo(0,1);
	LCD_WriteText("3s");
	_delay_ms(200);
	PORTA^= LEDy;
	_delay_ms(200);
	PORTA^= LEDy;
	_delay_ms(200);
	PORTA^= LEDy;
	_delay_ms(200);
	PORTA^= LEDy;
	_delay_ms(200);
	PORTA^= LEDy;
	LCD_GoTo(0,1);
	LCD_WriteText("2s");
	_delay_ms(200);
	PORTA^= LEDy;
	_delay_ms(200);
	PORTA^= LEDy;
	_delay_ms(200);
	PORTA^= LEDy;
	_delay_ms(200);
	PORTA^= LEDy;
	_delay_ms(200);
	PORTA^= LEDy;
	LCD_GoTo(0,1);
	LCD_WriteText("1s");
	_delay_ms(200);
	PORTA^= LEDy;
	_delay_ms(200);
	PORTA^= LEDy;
	_delay_ms(200);
	PORTA^= LEDy;
	_delay_ms(200);
	PORTA^= LEDy;
	_delay_ms(200);
	PORTA^= LEDy;
if(PINA & LEDy){
	PORTA^= LEDy;
}

}

void wysAlarm(){
LCD_Clear();
LCD_GoTo(4,0);
LCD_WriteText("ALARM !");
}

void stanUzbrojony(){
	if(PINA & LEDr){
		PORTA^= LEDr;
	}
	if(PINA & LEDy){
		PORTA^= LEDy;
	}
	PORTA ^= LEDy;
	LCD_Clear();
	LCD_GoTo(4,0);
	LCD_WriteText("Centrala");
	LCD_GoTo(4,1);
	LCD_WriteText("Uzbrojona");
}
